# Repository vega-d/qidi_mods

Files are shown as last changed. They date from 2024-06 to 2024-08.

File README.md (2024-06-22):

# qidi_mods
a set of mods to qidi printers. Assorted by model.

Each of the folders contains a printer.cfg, originally published by Qidi Tech, but modified by yours truly.

The changes I have done to printer.cfg files:
- speed up homing (40mm/s => 100mm/s)
- alter sensitivity during homing, homes with less noise
- use back left corner of the movement envelope
- alter Z homing for faster movement

## if you have not modified your printer.cfg
to apply this mod:
- download the printer.cfg for your printer (click green code button, download as zip, extract).
- connect your printer to your local network (wifi/ethernet).
- open Fluidd web interface of the printer.
- navigate to the configuration category.
- delete the existing printer.cfg file (right click).
- click upload, and select the printer.cfg for your printer out a folder you unzipped this project into.
- reboot the printer.
- home the printer, hover your finger over the red stop button for the first time in case it fails.
- if it didn't fail, you have now modded your printer into being a slightly better printer!
- if it does fail, please open a ticket under the issues tab of this repository. 

## if you HAVE modified your printer.cfg before
- you know what you're doing. Proceed. 
- if you do not know what you're doing, ask someone who does. You can reach out to me by email at msg@vega76.cz

## what is this ominous .tar.gz file in the repo?
I took the stock klipper install out of my x plus 3 and put it in a tarball.
On an offchance you accidentally clicked "update" in the fluidd webui of stock firmware and soft-bricked the printer, this is what y>
this command should extract the klipper install into a temp folder, wipe your existing one, and move my backup copy in place. then c>
```
cd /tmp && \
git clone https://github.com/vega-d/qidi_mods && \
tar -zxvf qidi_mods/stock-klipper.tar.gz -C /tmp/ && \
rm -rf /home/mks/klipper && \
mv -r /tmp/mnt/stockfw/home/mks/klipper /home/mks/
```

# credits:
- Thanks to https://github.com/DaNinjaSmurf for beta testing this on X plus 3
- Thanks to `argueforsport` on discord for providing measurements for X max 3

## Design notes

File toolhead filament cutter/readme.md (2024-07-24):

This mod depends on my custom homing procedure gcode available in the repo.
I recommend you print it out of the toughest material you have. I used 15% carbon fiber PA12 nylon. 

You will need

- 2x M3 10mm long bolts.
- 5mm boxcutter knife blade.
- PC4-M6 bowden tube holder.
- 5.5mm diameter spring.

You will also probably need a drill with 2mm and 3mm drill bits to round the holes, otherwise the printing artifacts may interfere with smooth action. 

klipper macro for unloading filament with this, for x plus 3, for other printers change the coordinates in G1 moves:
```
[gcode_macro UNLOAD_FILAMENT]
gcode:
    {% if printer.extruder.temperature < 210 %}
      M109 S250
    {% endif %}
    {% if printer.toolhead.homed_axes != "xyz" %}
      G28
    {% endif %}
    M117 Unloading Filament...
    G91
    G1 Z5
    G90
    G1 X260 Y10 F10000
    G4 P10
    G1 Y-20
    M83
    FORCE_MOVE STEPPER=extruder DISTANCE=70 VELOCITY=10
    G4 P10
    G1 Y10
    M117 Filament unloaded.
```

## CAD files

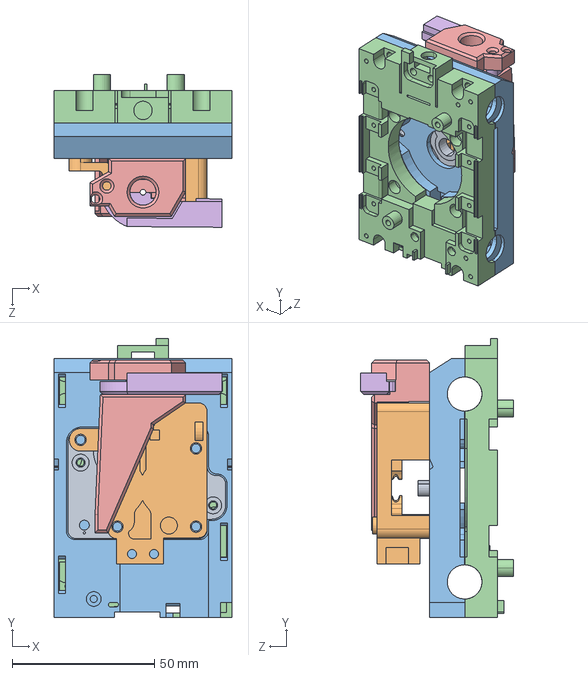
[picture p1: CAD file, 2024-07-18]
toolhead filament cutter/qidi cutter.SLDASM
62.4 x 98.0 x 53.6 mm
cutter body^qidi cutter
Part10^qidi cutter

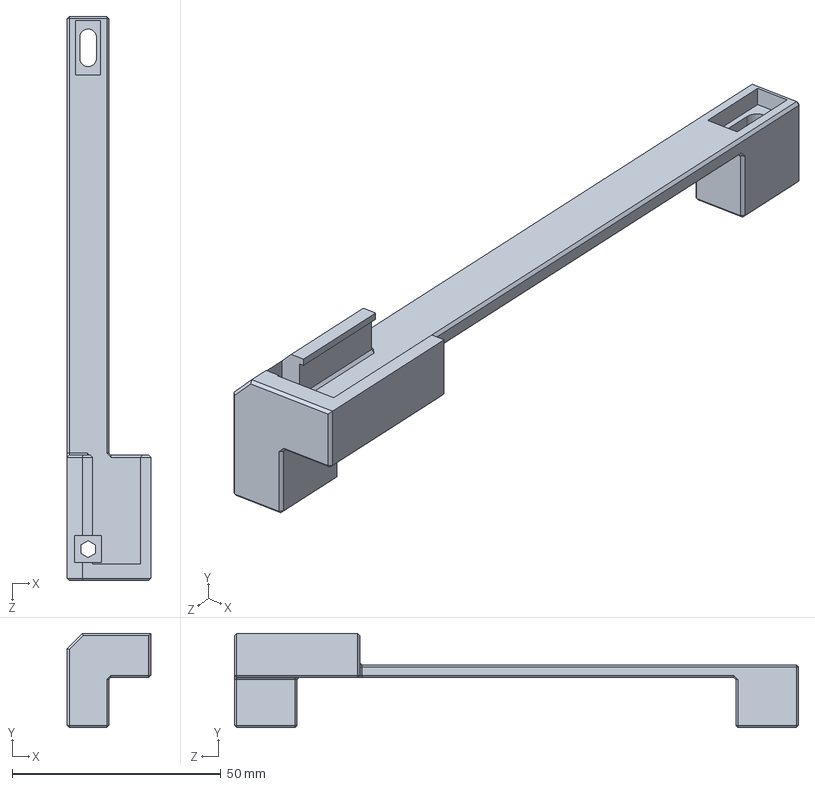
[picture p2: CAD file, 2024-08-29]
brush v2/brush v2.SLDPRT
20.0 x 22.5 x 135.0 mm

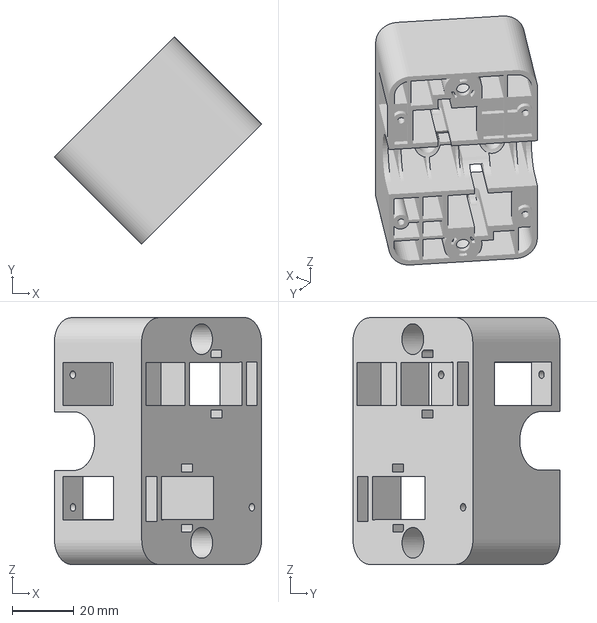
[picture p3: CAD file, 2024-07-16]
qidi 3d models/Gantry/Gantry_B.3mf
67.2 x 67.2 x 80.0 mm

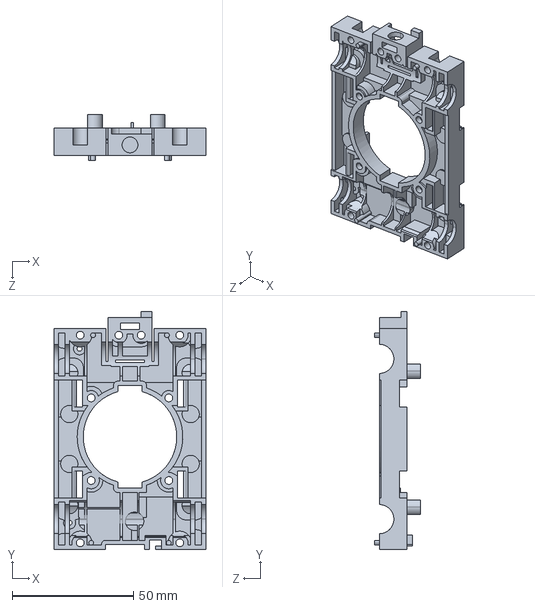
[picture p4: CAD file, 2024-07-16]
qidi 3d models/Toolhead/Linearplatte vorne Druckkopf.STEP
62.4 x 98.0 x 19.0 mm

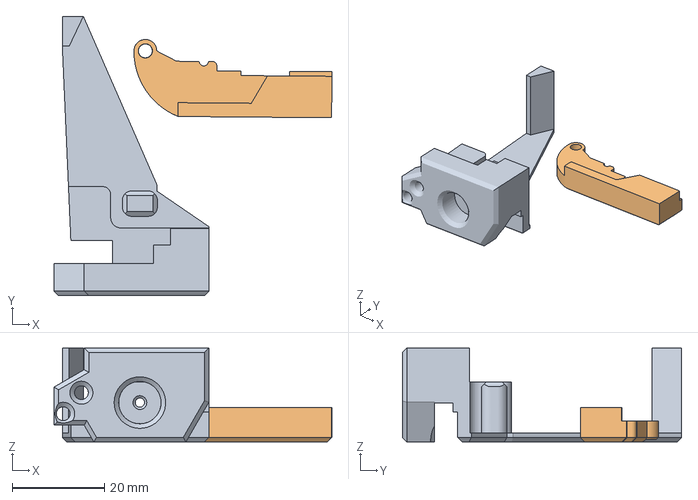
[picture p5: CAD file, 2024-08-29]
toolhead filament cutter/qidi toolhead.3MF
60.4 x 60.7 x 20.4 mm

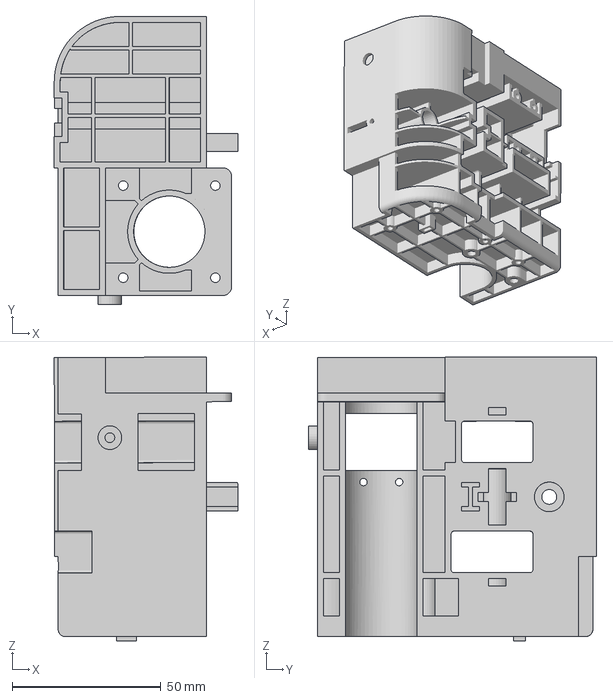
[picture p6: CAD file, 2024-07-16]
qidi 3d models/Gantry/Back_left.3mf
61.8 x 96.9 x 95.4 mm

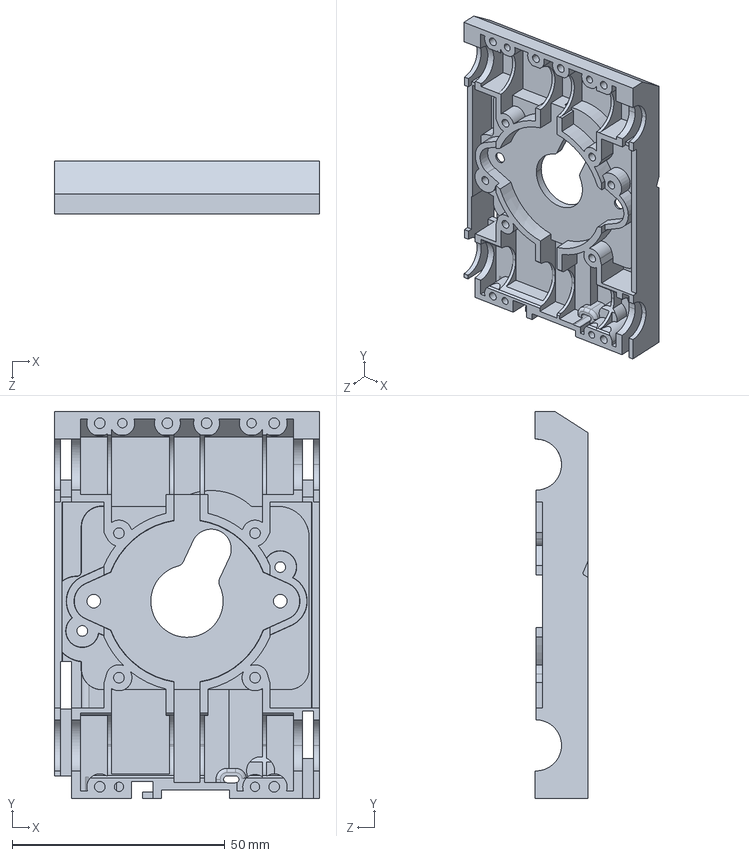
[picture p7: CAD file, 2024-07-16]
qidi 3d models/Toolhead/Linearplatte hinten Druckkopf.STEP
62.4 x 91.0 x 12.4 mm

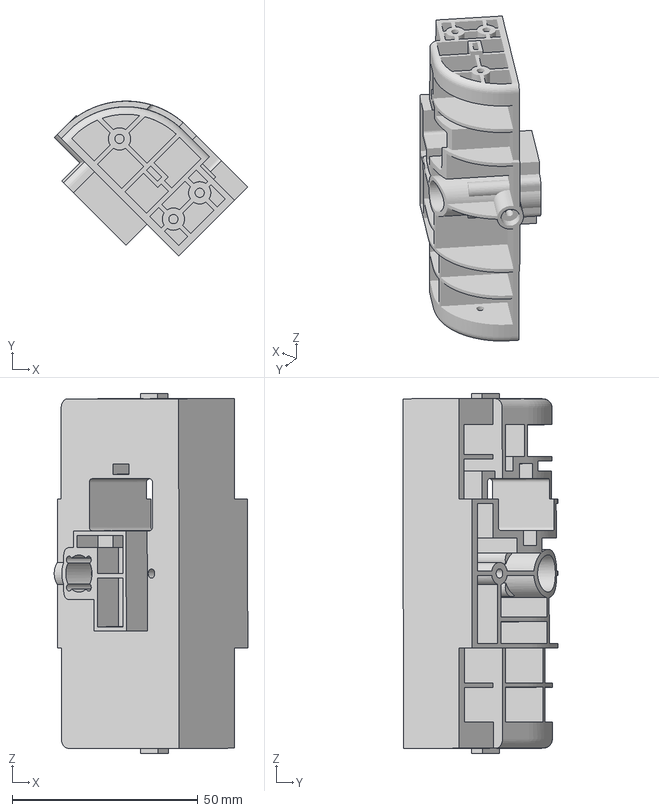
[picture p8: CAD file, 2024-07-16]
qidi 3d models/Gantry/Front_right.3mf
52.0 x 41.6 x 96.8 mm

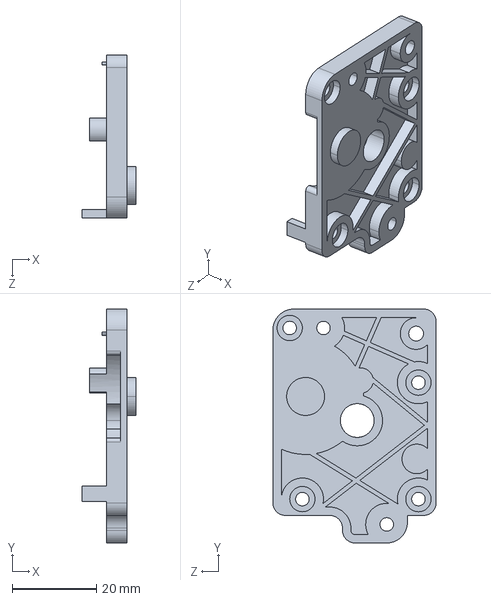
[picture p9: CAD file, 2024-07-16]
qidi 3d models/Toolhead/Extruder Rückwand.STEP
12.7 x 55.4 x 38.7 mm

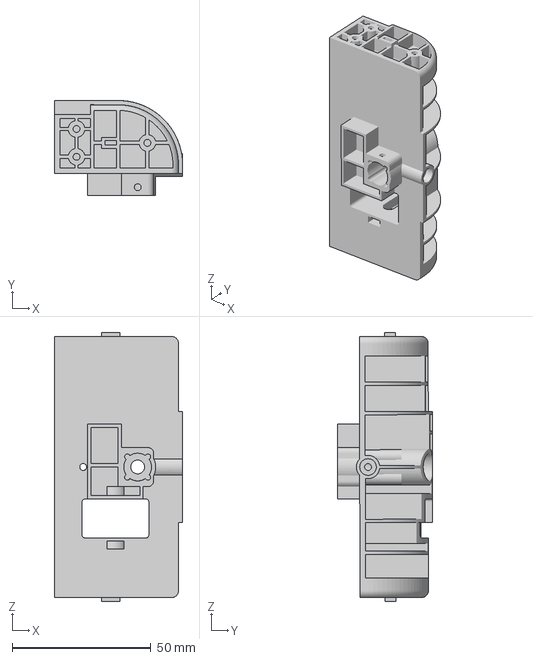
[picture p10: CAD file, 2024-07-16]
qidi 3d models/Gantry/Front_left.3mf
46.2 x 34.2 x 96.8 mm

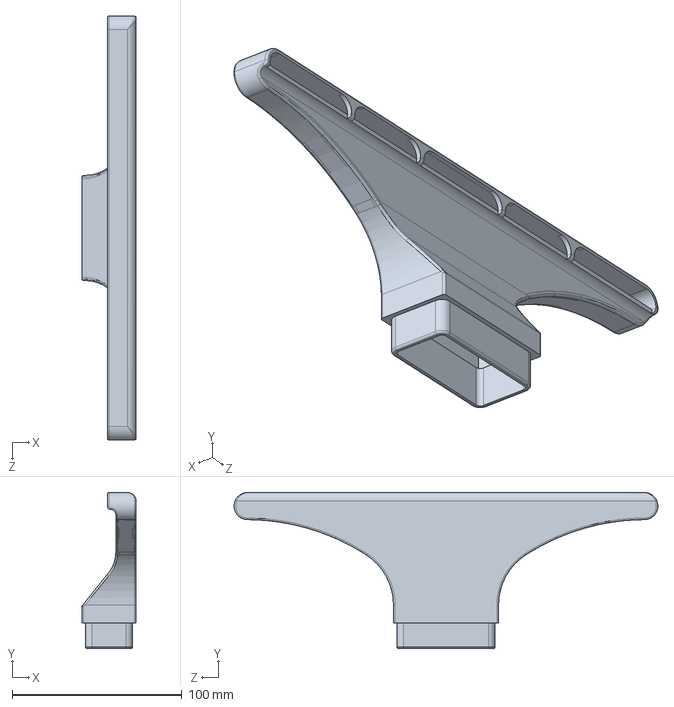
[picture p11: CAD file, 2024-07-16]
qidi 3d models/Toolhead/Cross fan nozzle right left.STEP
32.0 x 92.0 x 250.0 mm

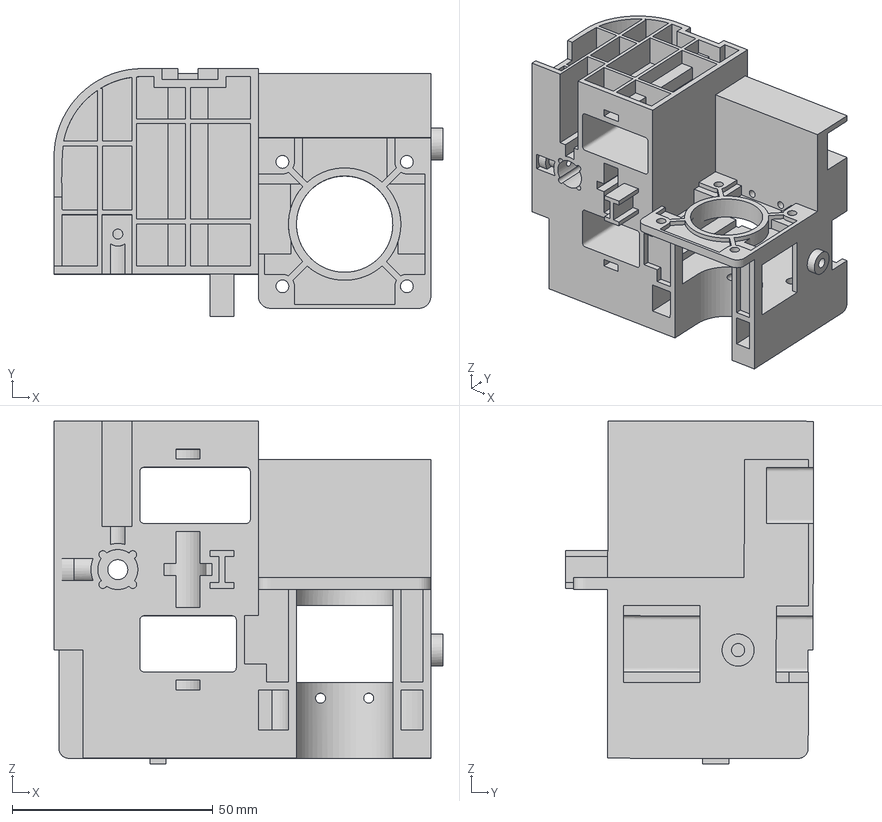
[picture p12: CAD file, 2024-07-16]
qidi 3d models/Gantry/Back_right.3mf
96.9 x 61.8 x 85.4 mm

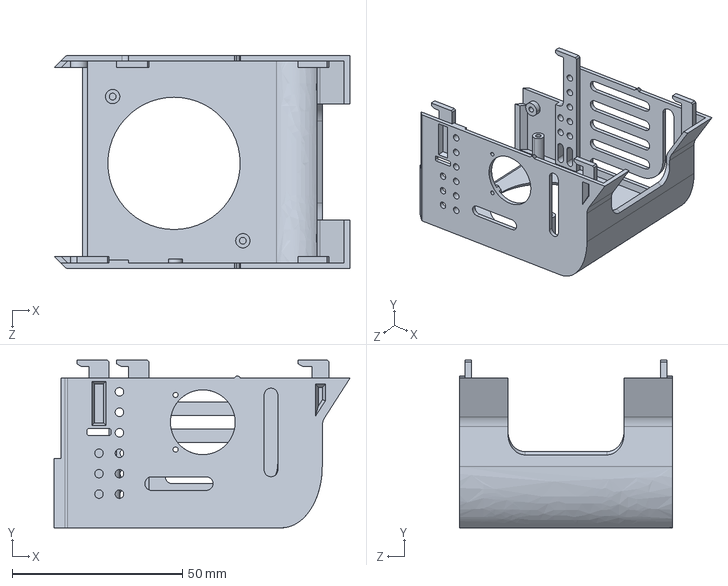
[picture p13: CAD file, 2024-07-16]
qidi 3d models/Toolhead/Druckkopfabdeckung vorne.STEP
86.8 x 49.2 x 62.4 mm

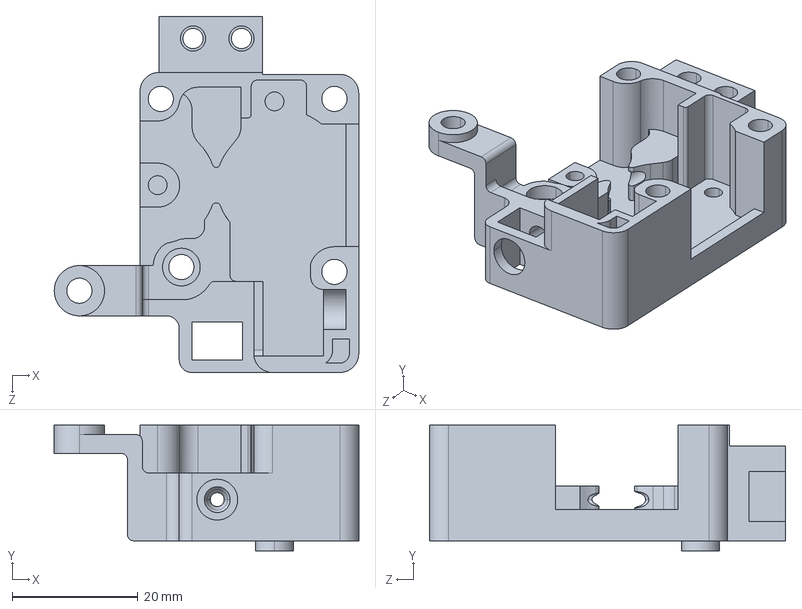
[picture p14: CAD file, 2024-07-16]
qidi 3d models/Toolhead/Extruder Mittelteil.STEP
48.4 x 20.0 x 56.6 mm

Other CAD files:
qidi 3d models/Gantry/Gantry_A.3mf
qidi 3d models/Toolhead/Typ-C Kabel Unterlage.STEP
qidi 3d models/Toolhead/Druckkopfabdeckung hinten.STEP
brush v2/brush v2.3MF
qidi 3d models/Gantry/Back_left.f3d
qidi 3d models/Gantry/Back_right.f3d
qidi 3d models/Gantry/Front_left.f3d
qidi 3d models/Gantry/Front_right.f3d
qidi 3d models/Gantry/Gantry_A.f3d
qidi 3d models/Gantry/Gantry_B.f3d

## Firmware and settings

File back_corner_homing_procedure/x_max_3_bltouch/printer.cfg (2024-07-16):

#MAX3
#V4.3.11
# https://github.com/vega-d/qidi_mods

[include MKS_THR.cfg]
[include Adaptive_Mesh.cfg]
[mcu]
# The hardware use USART1 PA10/PA9 connect to RK3328
#serial: /dev/serial/by-id/usb-Klipper_stm32f407xx_4D0045001850314335393520-if00
serial: /dev/ttyS0
restart_method: command



[extruder]
step_pin: MKS_THR:gpio5
dir_pin: MKS_THR:gpio4
enable_pin: !MKS_THR:gpio10
rotation_distance: 53.5  #22.6789511	#Bondtech 5mm Drive Gears
gear_ratio: 1628:170
microsteps: 16
full_steps_per_rotation: 200	#200 for 1.8 degree, 400 for 0.9 degree
nozzle_diameter: 0.400
filament_diameter: 1.75
min_temp: 0
max_temp: 360
min_extrude_temp: 170
smooth_time: 0.000001


heater_pin: MKS_THR:gpio0
sensor_type:MAX6675
#   One of "MAX6675", "MAX31855", "MAX31856", or "MAX31865".
#   One of "MAX6675", "MAX31855", "MAX31856", or "MAX31865".
sensor_pin:MKS_THR:gpio17
#   The chip select line for the sensor chip. This parameter must be
#   provided.
spi_speed: 100000
#   The SPI speed (in hz) to use when communicating with the chip.
#   The default is 4000000.
#spi_bus:spi1
spi_software_sclk_pin:MKS_THR:gpio18
spi_software_mosi_pin:MKS_THR:gpio19
spi_software_miso_pin:MKS_THR:gpio16
#   See the "common SPI settings" section for a description of the
#   above parameters.
#tc_type: K
#tc_use_50Hz_filter: False
#c_averaging_count: 1
#   The above parameters control the sensor parameters of MAX31856
#   chips. The defaults for each parameter are next to the parameter
#   name in the above list.
max_power: 1.0
control : pid
pid_Kp=14.734
pid_Ki=6.549 
pid_Kd=8.288

pressure_advance: 0.032
pressure_advance_smooth_time: 0.03
max_extrude_cross_section:500
instantaneous_corner_velocity: 10.000
max_extrude_only_distance: 120.0
max_extrude_only_velocity:5000
max_extrude_only_accel:2000
step_pulse_duration:0.000002


[tmc2209 extruder]
uart_pin: MKS_THR:gpio6
interpolate: True
run_current: 0.714
#hold_current: 0.5
#sense_resistor: 0.110
stealthchop_threshold: 0


[adxl345]
cs_pin: MKS_THR:gpio13
spi_software_sclk_pin: MKS_THR:gpio14
spi_software_mosi_pin: MKS_THR:gpio15
spi_software_miso_pin: MKS_THR:gpio12
axes_map: -x, z, -y



[printer]
kinematics:corexy
max_velocity: 600
max_accel: 20000
max_accel_to_decel: 10000
max_z_velocity: 20
max_z_accel: 500
square_corner_velocity: 8

##移动配置============================================================================================================

[force_move]
enable_force_move : True

[gcode_macro M84]
rename_existing:M84.1
gcode:
	SET_STEPPER_ENABLE STEPPER=stepper_x enable=0
	SET_STEPPER_ENABLE STEPPER=stepper_y enable=0
	SET_STEPPER_ENABLE STEPPER=stepper_z enable=0
	SET_STEPPER_ENABLE STEPPER=extruder enable=0
	SET_KINEMATIC_POSITION
	
[delayed_gcode KINEMATIC_POSITION]
initial_duration:0.2
gcode:
    SET_KINEMATIC_POSITION X=150
    SET_KINEMATIC_POSITION Y=150
	SET_KINEMATIC_POSITION Z=150
    SET_FILAMENT_SENSOR SENSOR=fila ENABLE=0



[stepper_x]
step_pin:PB4
dir_pin:PB3
enable_pin:!PB5
microsteps:16
rotation_distance: 39.94
full_steps_per_rotation:200  #set to 400 for 0.9 degree stepper
endstop_pin:tmc2209_stepper_x:virtual_endstop
position_min: -7
position_endstop:-7
position_max:325
homing_speed:100
homing_retract_dist:0
homing_positive_dir:False
step_pulse_duration:0.000002

[stepper_y]
step_pin:PC14
dir_pin:PC13
enable_pin:!PC15
microsteps: 16
rotation_distance: 39.94
full_steps_per_rotation:200  #set to 400 for 0.9 degree stepper
endstop_pin:tmc2209_stepper_y:virtual_endstop
position_min: -9.5
position_endstop: 350
position_max: 350
homing_speed:100
homing_retract_dist:0
homing_positive_dir:True
step_pulse_duration:0.000002



[stepper_z]
step_pin:PC10
dir_pin:PA15
enable_pin: !PC11
microsteps: 16
rotation_distance: 8
full_steps_per_rotation: 200
endstop_pin:probe:z_virtual_endstop#!PC3 #for Z-max; endstop have'!' is NO
#position_endstop:326
position_max:325
position_min: -6
homing_speed: 15
homing_retract_dist: 3
second_homing_speed: 2
homing_positive_dir:false
step_pulse_duration:0.000002

[tmc2209 stepper_x]
uart_pin: PD2
run_current:1.07
#hold_current: 0.5
interpolate: True
stealthchop_threshold: 0
diag_pin:^PB8
driver_SGTHRS: 150

[tmc2209 stepper_y]
uart_pin: PB9
run_current: 1.07
#hold_current: 0.5
interpolate: True
stealthchop_threshold: 0
diag_pin:^PC0
driver_SGTHRS: 150

[tmc2209 stepper_z]
uart_pin: PC5
run_current: 0.95
#hold_current: 0.6
interpolate: True
stealthchop_threshold: 1200

##归零流程修改
[homing_override]
set_position_X:0
set_position_y:0
set_position_z:0
axes:xyz
gcode: 
    {% set HOME_CUR = 0.5 %}
    {% set driver_config = printer.configfile.settings['tmc2209 stepper_x'] %}
    {% set RUN_CUR = driver_config.run_current %}
    {% set HOLD_CUR = driver_config.hold_current %}
    
    G91
    G1 Z5 Y5 F600    
    G4 P200
    
    SET_TMC_CURRENT STEPPER=stepper_x CURRENT={HOME_CUR * 0.8} 
    G28 X
    SET_TMC_CURRENT STEPPER=stepper_x CURRENT={HOME_CUR} 
    BEEP I=1 DUR=100  
    G1 X80 F8000
    
    SET_TMC_CURRENT STEPPER=stepper_y CURRENT={HOME_CUR * 0.9} 
    G28 Y
    SET_TMC_CURRENT STEPPER=stepper_y CURRENT={HOME_CUR} 
    BEEP I=1 DUR=100        

    G1 Y-50 F12000
    
    SET_TMC_CURRENT STEPPER=stepper_x CURRENT={HOME_CUR * 0.8} 
    G28 X
    SET_TMC_CURRENT STEPPER=stepper_x CURRENT={HOME_CUR} 
    BEEP I=1 DUR=100  
    
    G1 X50
    
    G28 Z
    BEEP I=1 DUR=100  
    SET_TMC_CURRENT STEPPER=stepper_x CURRENT={RUN_CUR} 
    SET_TMC_CURRENT STEPPER=stepper_y CURRENT={RUN_CUR} 
    M204 S20000
    G90
    G1 X0 Y0

##热床热腔==================================================================================================================

[heater_bed]
heater_pin:PC8
sensor_type: NTC 100K MGB18-104F39050L32
sensor_pin: PA0
max_power: 1.0
control = pid
pid_kp = 71.039
pid_ki = 2.223
pid_kd = 567.421
min_temp: -100
max_temp: 125

[heater_generic hot]
#gcode_id:
#   使用M105查询温度时使用的ID。
#   必须提供此参数。
heater_pin:PB10
max_power:1.0
sensor_type:NTC 100K MGB18-104F39050L32
sensor_pin:PA1


control = watermark
max_delta: 1.0
#pid_Kp=63.418 
#pid_Ki=1.342 
#pid_Kd=749.125

min_temp:-100
max_temp:70

[verify_heater hot]
max_error: 300
check_gain_time:480
hysteresis: 5
heating_gain: 1



[verify_heater extruder]
max_error: 120
check_gain_time:20
hysteresis: 5
heating_gain: 1

[verify_heater heater_bed]
max_error: 200
check_gain_time:60
hysteresis: 5
heating_gain: 1


##一些引脚定义======================================

##主板上大涡轮风扇
[output_pin fan2]
pin: PA8
pwm: True
cycle_time: 0.0100
hardware_pwm: false
value: 0.00
scale: 255
shutdown_value: 0.0

##喷头喉管风扇 50度自启动
#[heater_fan my_nozzle_fan1]
#pin:PC9
#max_power:1
#shutdown_speed:1
#cycle_time:0.05
#kick_start_time:0.05
#off_below:0
#heater:extruder
#heater_temp:50.0

##活性炭吹风扇
[output_pin fan3]
pin:PC9
pwm: True
cycle_time: 0.0100
hardware_pwm: false
value: 0.0
scale: 255
shutdown_value: 0.0


## FAN0  喉管风扇
[heater_fan hotend_fan]
pin:MKS_THR:gpio1
max_power: 1.0
kick_start_time: 0.5
heater: extruder
heater_temp: 50.0
fan_speed: 1.0
off_below: 0

[heater_fan hotend_fan2]
pin:MKS_THR:gpio20
max_power: 1.0
kick_start_time: 0.5
heater: extruder
heater_temp: 50.0
fan_speed: 1.0
off_below: 0

[heater_fan borad_fan]
pin:PC4
max_power: 1.0
kick_start_time: 0.5
heater: extruder
heater_temp: 50.0
fan_speed: 1.0
off_below: 0


## FAN0  吹模型风扇
[output_pin fan0]
pin: MKS_THR:gpio2
pwm: True
cycle_time: 0.0100
hardware_pwm: false
value: 0
scale: 255
shutdown_value: 0.0

##LED 灯
[output_pin caselight]
##  Chamber Lighting - In 5V-RGB Position
pin: PC7
pwm: false
shutdown_value:0
value:1
#cycle_time:0.01

[output_pin beeper]
##  Chamber Lighting - In 5V-RGB Position
pin: PA2
pwm: false
shutdown_value:0
value:0


[output_pin pwc]
pin: PA3
pwm: False
value: 1
shutdown_value: 1



##宏定义================================================================

[filament_switch_sensor fila]
pause_on_runout: True
runout_gcode:
            PAUSE
            SET_FILAMENT_SENSOR SENSOR=fila ENABLE=1
event_delay: 3.0
pause_delay: 0.5
switch_pin: !PC1

[bed_mesh]
speed:150               #调平速度
horizontal_move_z:10   #调平中Z抬高高度
mesh_min:22,15        #探测点最小位置
mesh_max:310,310      #探测点最大位置
probe_count:9,9      #调平点数
algorithm:bicubic
bicubic_tension:0.2
mesh_pps: 4, 4

[bltouch]
sensor_pin:^MKS_THR:gpio21
control_pin:MKS_THR:gpio11
stow_on_each_sample: False
#[probe]
#pin: ^!MKS_THR:gpio21
x_offset: 28
y_offset: 4.4
z_offset: 0.0
speed: 5
samples: 2
samples_result: average
sample_retract_dist: 3.0
samples_tolerance: 0.08
samples_tolerance_retries:3

#[gcode_macro G30]
#    G28
#    G1 X100 Y130 Z10
#    PROBE_CALIBRATE


[resonance_tester]
accel_chip:adxl345
probe_points:
    160, 160, 10  # an example

[gcode_macro SHAPER_CALIBRATE]
rename_existing: RESHAPER_CALIBRATE
gcode:
    RESHAPER_CALIBRATE FREQ_START=30 FREQ_END=150
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

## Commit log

2024-06-21 add Qidi X plus 3 support
    [printer.cfg]
2024-06-21 add Qidi X Max 3 support
    [printer.cfg]
2024-06-22 add stock klipper recovery option
2024-07-16 fix x max 3 configs (attempt 1)
    [printer.cfg]
2024-07-16 3d models.
    [Back_left.3mf, Back_left.f3d, Back_right.3mf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]
2024-07-18 qidi cutter mod
    [printer.cfg, qidi cutter.SLDASM, qidi toolhead.3MF]
2024-08-29 added brush v2 mod
    [brush v2.3MF, brush v2.SLDPRT, qidi toolhead.3MF]
